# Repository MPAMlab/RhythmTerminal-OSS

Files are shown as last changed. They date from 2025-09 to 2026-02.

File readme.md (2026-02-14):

# Rhythm Terminal

This is a project that can emulate a card reader and key inputs for certain rhythm games.

This project heavily referenced	codes from https://github.com/CrazyRedMachine/PN5180-cardio, based on that, we have implemented with more controlling buttons and a highly-customized case.

This project involved AI-generated codes.

aa5511b658bf76cf8556f8cab78fb582

## Tools

  - Arduino IDE
  - Sublime Text
  - Claude Code
  - SketchUp
  - MayCAD
  - AutoCAD

## Parts

  - Arduino Pro Micro
  - Elechouse PN532 NFC Module v3
  - 32mm Square Key Switches x5 (green x1, white x4)
  - 16mm Round Key Switches x2
  - 3x4 metrix Keypad
  - Key-operated Switch
  - Mounting HW

82ba645d9c2c8894c940d13b4632f811

211f9463077fa14a7ed7eba52bc14532

1e2303e4e792a5c2ec25c4b39c3cd5b6

Please note that the brands in the images are not endorsements or advertisements.

## Usage / Build

1. Wire everything up
2. Config & Flash the firmware with Arduino IDE
3. Build the aluminum profile frame and install the panel
4. Ready to go

## Special Thanks

[@KClbutHOSHiNO](https://github.com/HOSHiNOMONO) for physically frame build helping.

[@ZhuoLingBW](https://github.com/ZhuoLingBW) for physically wiring helping.

[@fish-cave](https://github.com/fish-cave) for location test helping.

The first product of Rhythm Terminal has been up running normally for about 2 months (until end of Nov 2025).

## License

This project is using GPL-3.0 license for code to keep the 'Same license' condition of repository PN5180-cardio, CC BY-SA-4.0 license for the documentations, images and multimedia, and CERN-OHL-W license for the Hardware Design. You can use or modify this project as long as you follow the license.

### License Transition Note

Prior to February 14, 2026, the Hardware Design was licensed under Creative Commons.

If you began an adaptation or derivative work under the previous license before this date, you may continue to use it under those terms.

All new adaptations, contributions, or distributions created after February 14, 2026, must adhere to the CERN-OHL-W license.

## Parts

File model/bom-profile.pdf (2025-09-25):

# CONSTRUCTION DOCUMENTATION

## Design Title : al-profile-maycad.scene

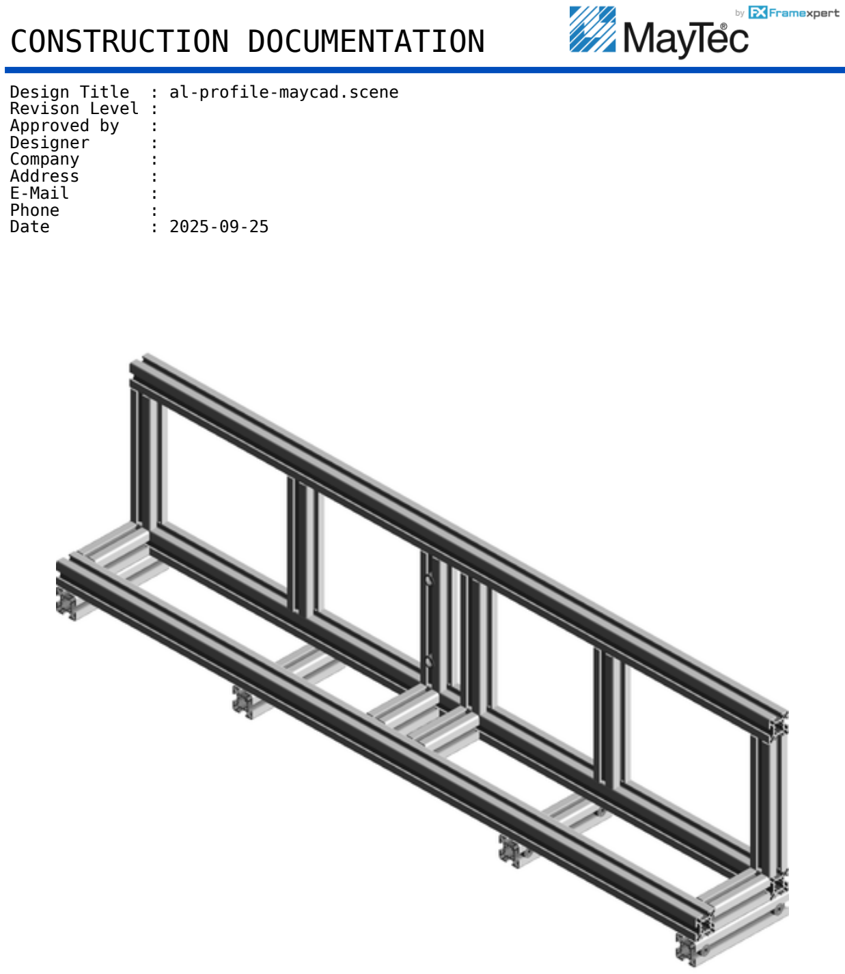
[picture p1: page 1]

## Revison Level :

Approved by | :
Designer | :
Company | :
Address | :
E-Mail | :
Phone | :
Date | : 2025-09-25

Pos | Article-No | Description | Units | Qty
1 | 1.11.030030.43LP-A00A00/140 | Profile 30x30, 4F, light, plain | MM | 1
2 | 1.11.030030.43LP-A00A00/140 | Profile 30x30, 4F, light, plain **PER DRAWING 1** | MM | 1
2.A | ZA4/15.0 | Parallel-connector distance left: 15.0 mm, anchor on side: 1 | EA | 1
2.B | ZA4/125.0 | Parallel-connector distance left: 125.0 mm, anchor on side: 1 | EA | 1
3 | 1.11.030030.43LP-AA1AA1/160 | Profile 30x30, 4F, light, plain | MM | 1
4 | 1.11.030030.43LP-AA3AA3/160 | Profile 30x30, 4F, light, plain | MM | 1
5 | 1.11.030030.43LP-A00A00/960 | Profile 30x30, 4F, light, plain | MM | 1
6 | 1.11.030030.43LP-A00A00/80 | Profile 30x30, 4F, light, plain **PER DRAWING 2** | MM | 2
6.A | ZA4/40.0 | Parallel-connector distance left: 40.0 mm, anchor on side: 3 | EA | 2
7 | 1.11.030030.43LP-A00A00/80 | Profile 30x30, 4F, light, plain | MM | 2
8 | 1.11.030030.43LP-A00A00/140 | Profile 30x30, 4F, light, plain **PER DRAWING 3** | MM | 2
8.A | ZA4/15.0 | Parallel-connector distance left: 15.0 mm, anchor on side: 3 | EA | 2
8.B | ZA4/125.0 | Parallel-connector distance left: 125.0 mm, anchor on side: 3 | EA | 2
9 | 1.11.030030.43LP-A00A00/960 | Profile 30x30, 4F, light, plain **PER DRAWING 4** | MM | 2
9.A | ZA4/15.0 | Parallel-connector distance left: 15.0 mm, anchor on side: 1 | EA | 2
10 | 1.11.030030.43LP-AA4AA4/160 | Profile 30x30, 4F, light, plain | MM | 4
11 | 1.21.3F0 | Connector, universal | EA | 12
12 | 1.21.3F5 | Connector, parallel-square | EA | 10
Total Weight: | 5.09 kg (11.22 lbs)
Version : 11.340.00, Build: 281 (64-bit Windows) | Page 2
Design Title | : al-profile-maycad.scene
Customer Name | :
Date | : 2025-09-25

## Construction documentation

# Bill of materials (Number of kits: 1)

Design Title | : al-profile-maycad.scene
Customer Name | :

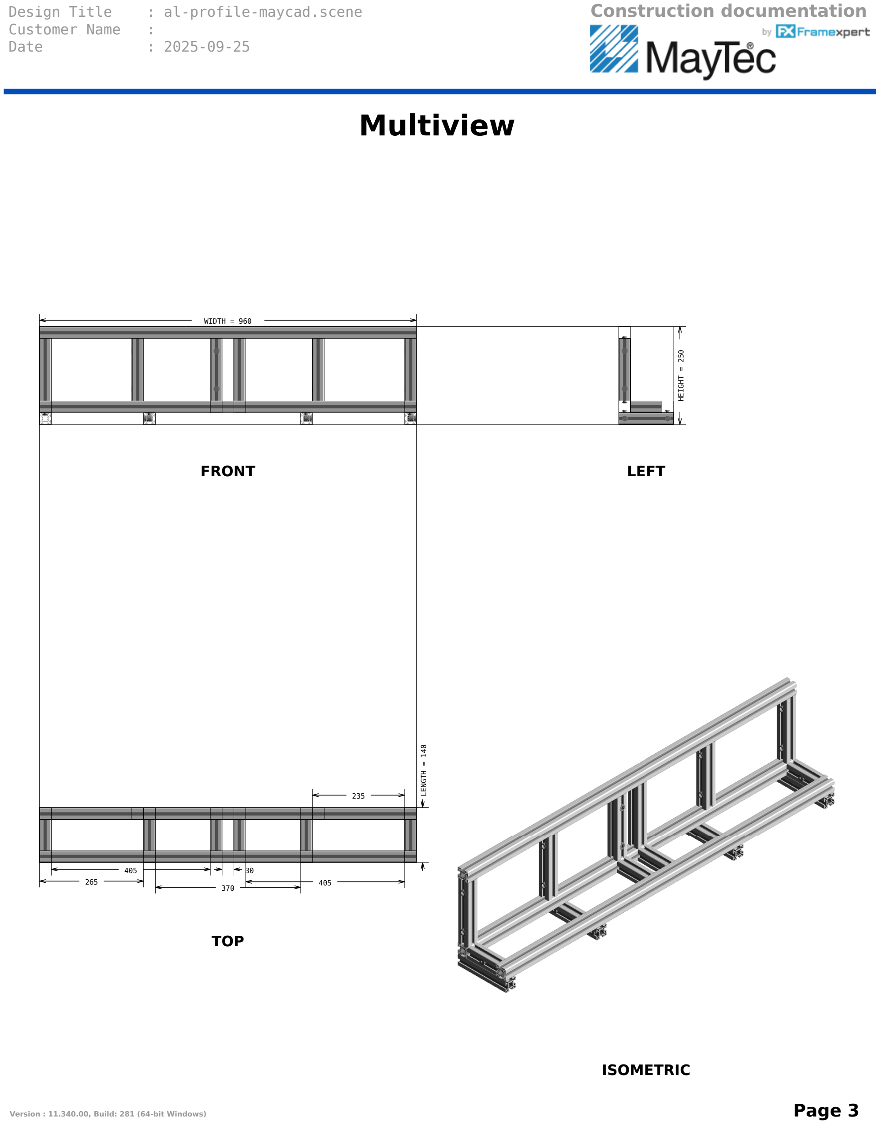
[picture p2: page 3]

WIDTH = 960

### FRONT

HEIGHT = 250

### LEFT

30

235

265
370

405
405

LENGTH = 140

### TOP

### ISOMETRIC

Version : 11.340.00, Build: 281 (64-bit Windows) | Page 3
Date | : 2025-09-25

## Construction documentation

# Multiview

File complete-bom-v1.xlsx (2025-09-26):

type | model | qty | unit price | total
Shell HW | 3030Q alm. profile bar (europe standard) | 1 | 130 | 130
 | front panel | 1 | 150 | 150
 | mounting hw | 1 | 108.29 | 108.29
Electronic HW | Sparkfire Arduino Pro Micro(5v, typec) | 2 | 22.85 | 45.7
 | Dupont wire(1-5 for GND expansion) | 2 | 10.08 | 20.16
 | keypad(3*4) | 2 | 7.6 | 15.2
 | pn532 module | 2 | 12.24 | 24.48
 | 32mm key switches | 10 | 1.75 | 17.5
 | dupont wire(4.8mm for key switches) | 10 | 0.5 | 5
 | 16mm key switches | 2 | 1.6 | 3.2
 | dupont wire(2.8mm for key switches) | 2 | 1 | 2
 | lock switches | 1 | 5 | 5
 | dupont wire (for rest parts) | 1 | 10 | 10
total |  |  |  | 536.53

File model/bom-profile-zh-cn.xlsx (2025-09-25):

长度(mm) | 数量 | 总长(mm) | 重量(kg) | 单价（元/m） | 总计（元） | 假设损耗 | 总计-计损耗（元）
140 | 4 | 560 | 0.448 | N/A
80 | 4 | 320 | 0.256
160 | 6 | 960 | 0.768
960 | 3 | 2880 | 2.304
总计 | 17 | 4720 | 3.776 | 19.7 | 92.984 | 7% | 99.49288
欧标3030Q-喷砂黑
两条140的型材上钻两个m8孔 | 距一端位置： | 14mm | 85mm | 下图中红圈处为需要打孔的型材

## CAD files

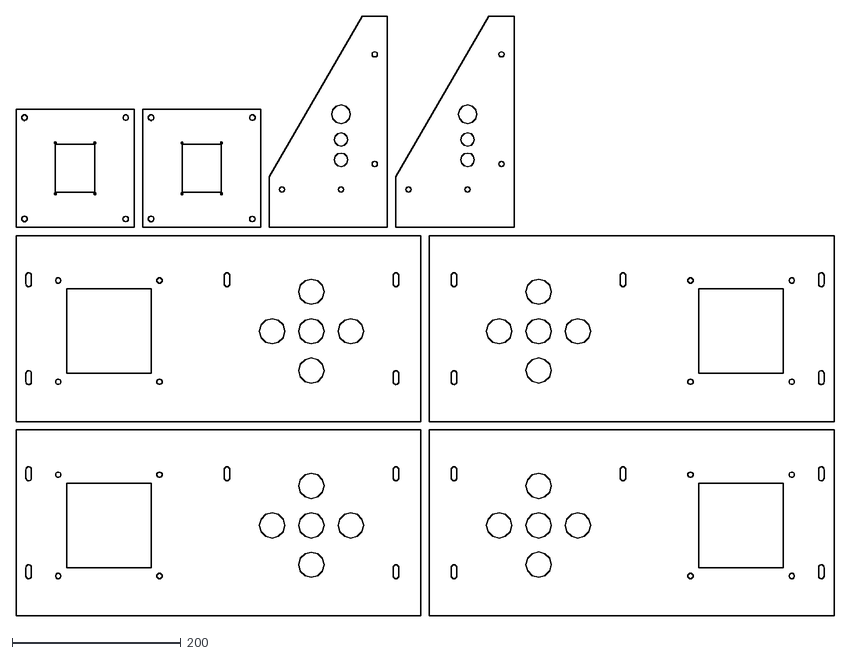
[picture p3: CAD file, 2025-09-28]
model/front-plate-cutout.dxf
969.0 x 710.0

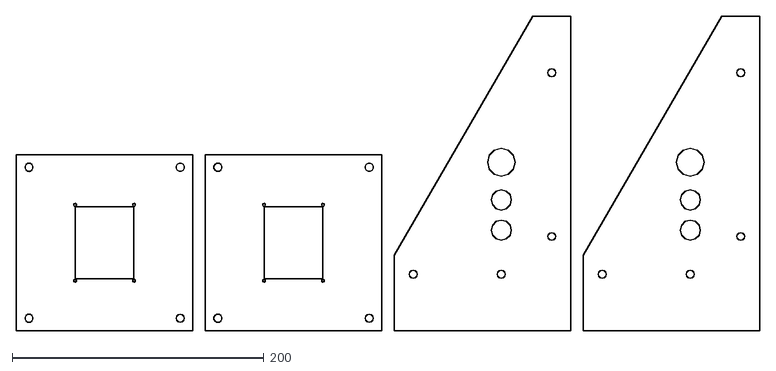
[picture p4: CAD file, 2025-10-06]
model/20250929.dxf
590.0 x 250.0

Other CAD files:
model/plate-design-cad-cutout.skp
model/plate-design-cad.skp

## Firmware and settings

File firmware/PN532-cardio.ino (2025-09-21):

#include "Config.h"
#include <Wire.h>
#include "src/PN532/PN532_I2C.h"
#include "src/PN532/PN532.h"
#include "src/Cardio.h"
#include "BUNDLEHID.h"

PN532_I2C pn532i2c(Wire);
PN532 nfc(pn532i2c);

Cardio_ Cardio;

#if WITH_KEYPAD == 1
  /* Keypad declarations with new layout according to requirements */
  const char numpad[4][3] = {
   {'2', '1', '3'},    // GP14 row
   {'0', '\337', ','}, // GP18 row
   {'8', '7', '9'},    // GP20 row
   {'5', '4', '6'}     // GP21 row
  };

  uint8_t rowPins[4] = {PIN_ROW1, PIN_ROW2, PIN_ROW3, PIN_ROW4};
  uint8_t colPins[3] = {PIN_COL1, PIN_COL2, PIN_COL3};
#endif

#if WITH_NAVBUTTONS == 1
  uint8_t navPins[8] = {
    PIN_NAV1, PIN_NAV2, PIN_NAV3, PIN_NAV4,
    PIN_NAV5, PIN_NAV6, PIN_NAV7, PIN_NAV8
  };
#endif
 
void setup() {
  Serial.begin(115200);
  Serial.println("PN532-cardio starting...");

  /* Initialize BUNDLEHID */
#if WITH_KEYPAD == 1 || WITH_NAVBUTTONS == 1
  Serial.println("Initializing BUNDLEHID...");
  #if WITH_KEYPAD == 1 && WITH_NAVBUTTONS == 1
    BUNDLEHID.begin(rowPins, colPins, navPins);
    Serial.println("BUNDLEHID initialized with keypad and nav buttons");
  #elif WITH_KEYPAD == 1
    BUNDLEHID.begin(rowPins, colPins, NULL);
    Serial.println("BUNDLEHID initialized with keypad only");
  #elif WITH_NAVBUTTONS == 1
    BUNDLEHID.begin(NULL, NULL, navPins);
    Serial.println("BUNDLEHID initialized with nav buttons only");
  #endif
#endif

/* NFC */
  nfc.begin();

  uint32_t versiondata = nfc.getFirmwareVersion();
  if (!versiondata)
  {
Serial.print("Didn't find PN53x board");
    while (1) {delay(10);};      // halt
  }

  // Set the max number of retry attempts to read from a card
  // This prevents us from waiting forever for a card, which is
  // the default behaviour of the PN532.
  nfc.setPassiveActivationRetries(0xFF);
  nfc.SAMConfig();

//  memset(_prevIDm, 0, 8);

  Cardio.begin(false);
  Serial.println("Cardio initialized");
}

unsigned long lastReport = 0;
uint16_t cardBusy = 0;
unsigned long lastPollTime = 0;
unsigned long pollCount = 0;

// read cards loop
void loop() {
  /* Update BUNDLEHID - always call first for maximum responsiveness */
#if WITH_KEYPAD == 1 || WITH_NAVBUTTONS == 1
  BUNDLEHID.update();

  // Track polling rate
  pollCount++;
  if (millis() - lastPollTime >= 1000) {
    Serial.print("Polling rate: ");
    Serial.print(pollCount);
    Serial.println(" Hz");
    pollCount = 0;
    lastPollTime = millis();
  }
#endif

  /* NFC */
  if (millis()-lastReport < cardBusy) return;

  cardBusy = 0;
  uint8_t uid[8] = {0,0,0,0,0,0,0,0};
  uint8_t hid_data[8] = {0,0,0,0,0,0,0,0};
  uint8_t uidLength;                        // Length of the UID (4 or 7 bytes depending on ISO14443A card type)

  // check for FeliCa card
  uint8_t ret;
  uint16_t systemCode = 0xFFFF;
  uint8_t requestCode = 0x01;       // System Code request
  uint8_t idm[8];
  uint8_t pmm[8];
  uint16_t systemCodeResponse;

  // Check for FeliCa card
  ret = nfc.felica_Polling(systemCode, requestCode, idm, pmm, &systemCodeResponse, NFC_FELICA_TIMEOUT);

    if (ret == 1) {
      Serial.print("FeliCa card detected - IDm: ");
      for (int i = 0; i < 8; i++) {
        if (idm[i] < 0x10) Serial.print("0");
        Serial.print(idm[i], HEX);
      }
      Serial.print(" SystemCode: 0x");
      Serial.println(systemCodeResponse, HEX);

      Cardio.setUID(2, idm);
      Cardio.sendState();
      lastReport = millis();
      cardBusy = 3000;
      uidLength = 0;
      return;
    }

   // check for ISO14443 card
    if (nfc.readPassiveTargetID(PN532_MIFARE_ISO14443A, &uid[0], &uidLength, NFC_ISO14443_TIMEOUT)) {
      Serial.print("ISO14443A card detected - UID: ");
      for (int i = 0; i < uidLength; i++) {
        if (uid[i] < 0x10) Serial.print("0");
        Serial.print(uid[i], HEX);
      }
      Serial.print(" (Length: ");
      Serial.print(uidLength);
      Serial.println(" bytes)");

      // Apply UID masking for compatibility (like PN5180 implementation)
      uid[0] &= 0x0F; // some games won't accept cards with a first byte higher than 0x0F

      for (int i=0; i<8; i++) {
        hid_data[i] = uid[i%uidLength];
      }
      // Report as type 2 (FeliCa) for maximum compatibility
      Cardio.setUID(2, hid_data);
      Cardio.sendState();
      lastReport = millis();
      cardBusy = 3000;
      return;
    }
  // no card detected - reduced delay for better keypad responsiveness
  lastReport = millis();
  cardBusy = NFC_NO_CARD_DELAY;  // Delay between NFC polling cycles
}

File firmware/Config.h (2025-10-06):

#ifndef CONFIG_h
#define CONFIG_h

/* ISO14443 support (for older Aime/Nesica/BANAPASSPORT cards... reader will pretend it was a FeliCa for maximum cardio compatibility) */
#define WITH_ISO14443 1

/* Use a matrix keypad with new HID implementation */
#define WITH_KEYPAD 1
  /* New keypad pinout - Rows: GP14, GP18, GP20, GP21; Columns: GP16, GP15, GP19 */
  #define PIN_ROW1 14    // GP14
  #define PIN_ROW2 18    // GP18
  #define PIN_ROW3 20    // GP20
  #define PIN_ROW4 21    // GP21
  #define PIN_COL1 16    // GP16
  #define PIN_COL2 15    // GP15
  #define PIN_COL3 19    // GP19

/* Navigation buttons (8 independent joystick buttons) */
#define WITH_NAVBUTTONS 1
  #define PIN_NAV1 1     // GP1
  #define PIN_NAV2 4     // GP4
  #define PIN_NAV3 5     // GP5
  #define PIN_NAV4 6     // GP6
  #define PIN_NAV5 7     // GP7
  #define PIN_NAV6 8     // GP8
  #define PIN_NAV7 9     // GP9
  #define PIN_NAV8 10    // GP10

/* Player ID (1 or 2) */
#define CARDIO_ID 2
/* Enable custom VID/PID (will require to hold reset button to reflash firmware) */
#define CUSTOM_VIDPID 1

/* NFC polling timeouts (in milliseconds) */
#define NFC_FELICA_TIMEOUT 10     // FeliCa polling timeout
#define NFC_ISO14443_TIMEOUT 10   // ISO14443A polling timeout
#define NFC_NO_CARD_DELAY 100     // Delay between polling cycles

#endif

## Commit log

2025-09-21 fix original repo has iso14443a read problem
    fix via methods from pn5180 branch
    [Config.h, PN532-cardio.ino]
2025-09-25 update cad model
    [bom-profile-zh-cn.xlsx, front-plate-cutout.dwg, plate-design-cad-cutout.skp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]
2025-09-25 slight change
    [bom-profile-zh-cn.xlsx, front-plate-cutout.dwg, front-plate-cutout.dxf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]
2025-09-28 update cutout
    [front-plate-cutout.dxf, plate-design-cad-cutout.skp]
2025-10-06 update usb joystick number overflow problem
    also updated model
    [20250929.dxf, plate-design-cad.skp]
2025-10-06 readme.md を更新
